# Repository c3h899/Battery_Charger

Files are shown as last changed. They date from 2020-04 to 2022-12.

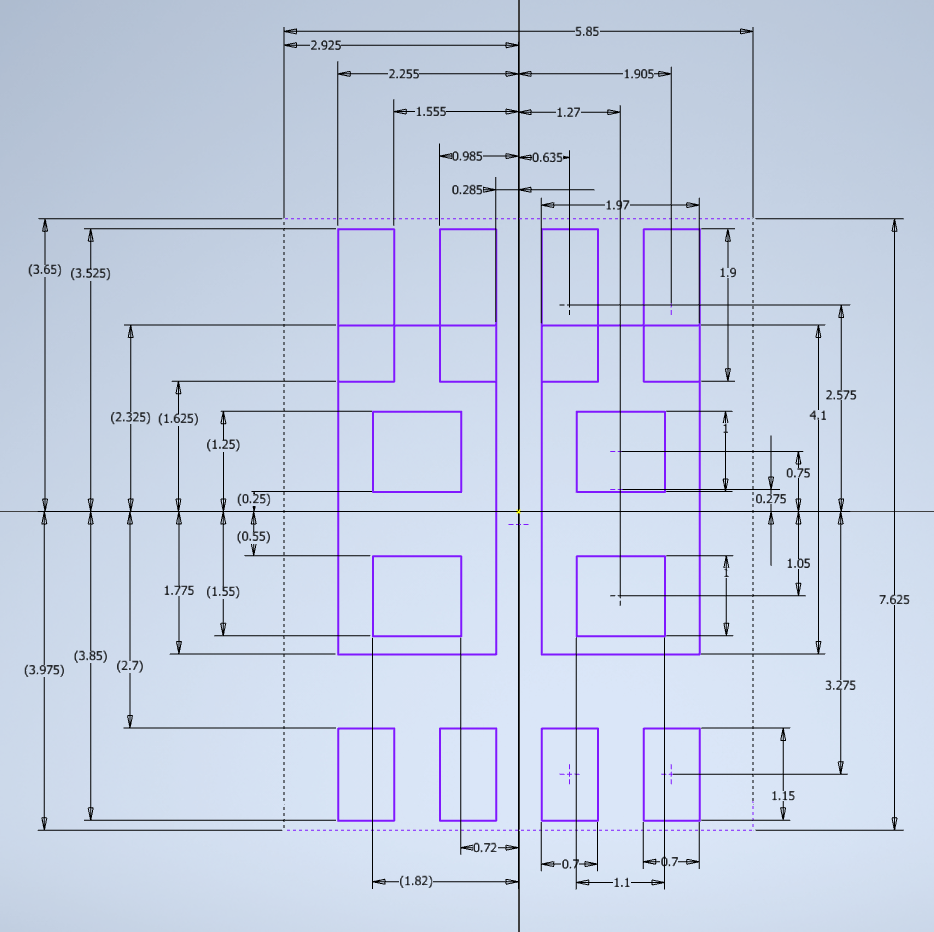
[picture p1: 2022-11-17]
DataSheets/Abs_vs_Center+Dist.PNG

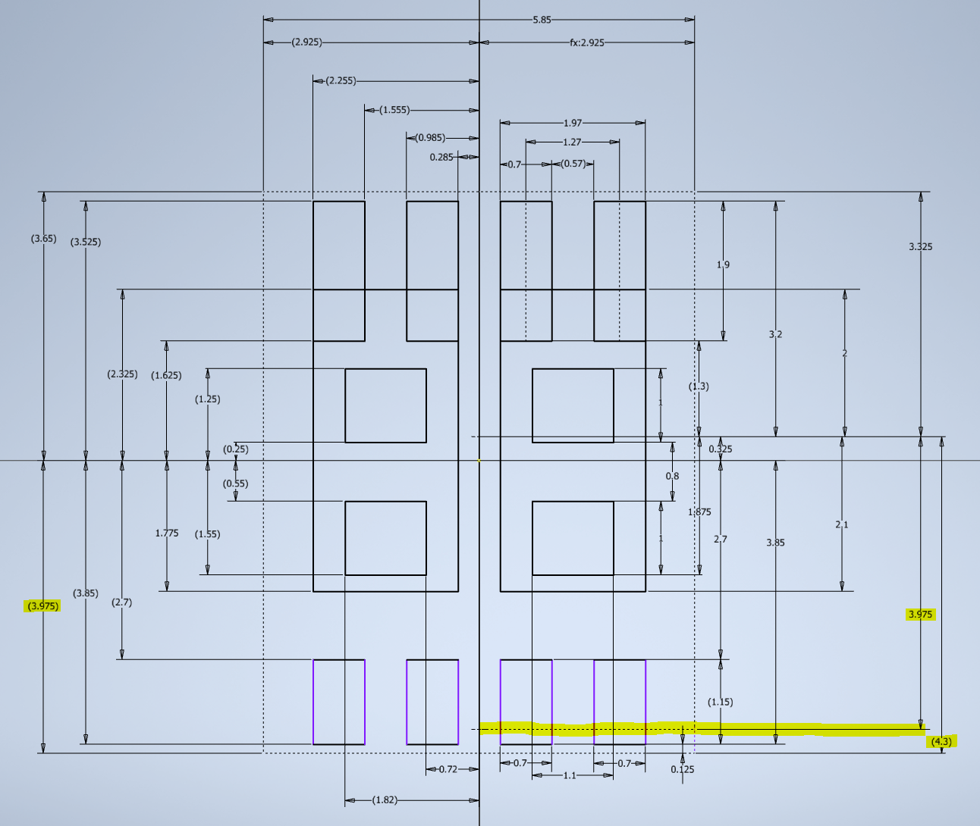
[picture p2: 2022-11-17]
DataSheets/Direct_Compair.PNG

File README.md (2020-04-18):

# Battery_Charger
- Battery Charger for (14.4 and 18.0) V NiMH Tool Batteries *Experimental*
- Requires External 24+ V, 2 A, DC power supply.

## Revision 3
- Adjusted Footprints.
- Bias network for RV1 adjusted.
- Bleed resistors added to large capacitors.
- Cascode circuitry added to +BATT monitoring to protect MAX713 sense input.
- D2 replaced with Q2 to provide more ideal diode behavior and provide reverse input protection.
- External temperature monitoring circuitry added.
- Low pass RC filters added to +BATT and -BATT sensing pins.
- Reverse input protection added to the DC input and Battery Outputs using P-Channel power MOSFETs.

## Revision 2
- Restructured board to have separate analog and switching ground planes (stared)

## Prototype 0
- Resistor Footprints are WAY too big.
- MAX713 Will regulate voltage across BAT- to BAT+ when measured using resistive load.
- Device successfully achieves current regulation during fast charge.
- At 24 V DC Input the LM7805 Gets hot, may need heatsink.
- Q2 was originally a 1N4001; Replace with 1N5821 due to excessive heating.
- Target Batteries get HOT near end-of charge sequence.
- Device has **NOT** been observed to perform DV/dt charge termination.
- In absence of reverse input protection, installing a charged battery backwards will destroy R7...R10.

## Revision 0
- Design is experimental, based on MAX713 Charge Controller.
- Concept: Replace the Linear Regulated Supply with a Buck Converter.
- Design is intended to charge at C/2 (~1.8 A)
- No use of temperature feedback is employed.
- No effort is made to reverse-input protect board.

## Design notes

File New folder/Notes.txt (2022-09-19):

NiCd
---
Charged ~1.6 V

NiMH
---
DV Goes Negative
Charged ~1.5 V

Universal
---
Undervolt 1.0 V (Arbitrary)
Nominal 1.2 V
Charged 1.5 V
DESIGN MAX 1.7 V

Trickel ~ 0.05 C
Standard Charge ~ 0.1 C
Quick Charge ~ 0.5 C
Rapid Charge ~ 1.0 C

Cell Counts

14.4 V Nominal
---
12 Cells
18 V @ 1.5 V
20.4 V @ 1.7

18.0 V Nominal
---
15 Cells
22.5 V @ 1.5 V

DESIGN
---
Series Buck + Boost Arangement
Goals: Continuous Conduction
Assume 3.6 Ah Capacity
1.8 A Design Current (1/2 C Quick Charge)
180 mA (1/20 C Trickel)

Frequency of Operation 300 kHz

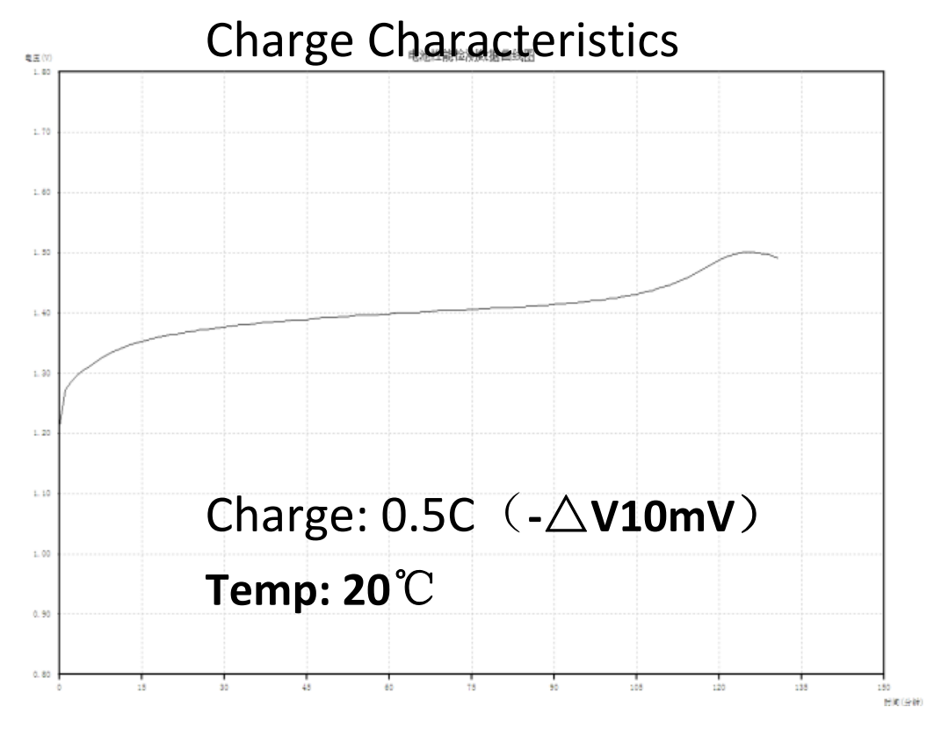
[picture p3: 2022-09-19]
New folder/NiMH Sub-S.PNG

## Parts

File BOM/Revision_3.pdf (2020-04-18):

Quantity Type | Description | Manufacturer Part Number | Vendor | Vendor Part Number | Unit Price Extended Price
2 | Capacitor | CAP CER 10000PF 100V X7R RADIAL | C315C103K1R5TA7301 | Digi‐Key | 399‐9857‐1‐ND | 0.27 | 0.54
1 | Capacitor | CAP ALUM 470UF 20% 50V RADIAL | ESW477M050AL3AA | Digi‐Key | 399‐6117‐ND | 1.04 | 1.04
3 | Capacitor | CAP ALUM 10UF 10% 63V RADIAL | UKL1J100KED | Digi‐Key | 493‐14491‐ND | 0.42 | 1.26
3 | Capacitor | CAP ALUM 1UF 10% 100V RADIAL | UKL2A010KDD | Digi‐Key | 493‐15407‐ND | 0.35 | 1.05
1 | Diode Schottky | DIODE SCHOTTKY 30V 3A DO201AD | 1N5821RLG | Digi‐Key | 1N5821RLGOSCT‐ND | 0.40 | 0.40
1 | IC | IC REG BUCK ADJ 3A TO263‐7 | LM2676SX‐ADJ/NOPB | Digi‐Key | LM2676SX‐ADJ/NOPBCT‐ND | 4.77 | 4.77
1 | IC | IC REG LINEAR 5V 1A TO220‐3 | LM7805CT/NOPB | Digi‐Key | 296‐47192‐ND | 1.54 | 1.54
1 | IC | IC BATT FASTCHRG NICD/NIMH16SOIC | MAX713CSE+ | Digi‐Key | MAX713CSE+‐ND | 5.87 | 5.87
1 | Inductor | FIXED IND 68UH 7.3A 25 MOHM | 1468373C | Digi‐Key | 811‐3857‐ND | 2.62 | 2.62
2 | MOSFET P.Ch | MOSFET P‐CH 60V 27A TO‐220 | FQP27P06 | Digi‐Key | FQP27P06‐ND | 1.41 | 2.82
1 | NPN | TRANS NPN 40V 0.2A TO92 | 2N3904‐AP | Digi‐Key | 2N3904‐APCT‐ND | 0.17 | 0.17
1 | Potentiometer | POT 10K OHM 1/20W CARBON LINEAR | PTV09A‐4020U‐B103 | Digi‐Key | PTV09A‐4020U‐B103‐ND | 0.83 | 0.83
3 | Resistor | RES 100K OHM 0.4W 1% AXIAL | MBA02040C1003FRP00 | Digi‐Key | BC100KXCT‐ND | 0.24 | 0.72
8 | Resistor | RES 27K OHM 0.4W 1% AXIAL | MBA02040C2702FCT00 | Digi‐Key | BC3267CT‐ND | 0.24 | 1.92
2 | Resistor | RES 10K OHM 1/4W 1% AXIAL | RNMF14FTC10K0 | Digi‐Key | S10KCACT‐ND | 0.10 | 0.20
3 | Resistor | RES 18K OHM 1/4W 1% AXIAL | RNMF14FTC18K0 | Digi‐Key | S18KCACT‐ND | 0.10 | 0.30
2 | Resistor | RES 1K OHM 1/4W 1% AXIAL | RNMF14FTC1K00 | Digi‐Key | S1KCACT‐ND | 0.10 | 0.20
1 | Resistor | RES 43K OHM 1/4W 1% AXIAL | RNMF14FTC43K0 | Digi‐Key | S43KCACT‐ND | 0.10 | 0.10
4 | Resistor | RES 0.56 OHM 1W 5% AXIAL | RSMF1JTR560 | Digi‐Key | RSMF1JTR560CT‐ND | 0.24 | 0.96
1 | Resistor NTC | THERMISTOR NTC 10KOHM 3977K BEAD | NTCLE100E3103JB0 | Digi‐Key | BC2301‐ND | 0.69 | 0.69
3 | PCB | Printed Circuit Board | Charge_Board_R3 | OshPark | | 14.93 | 44.79
| | | | | | | 72.79
| | | | | | | 6.01
| Shipping | | | OshPark | | 6.70 | 6.70
| Shipping | | | Digi‐Key | | 8.99 | 8.99
| | | | | | | 94.49

Sub‐Total
Sales Tax

Total

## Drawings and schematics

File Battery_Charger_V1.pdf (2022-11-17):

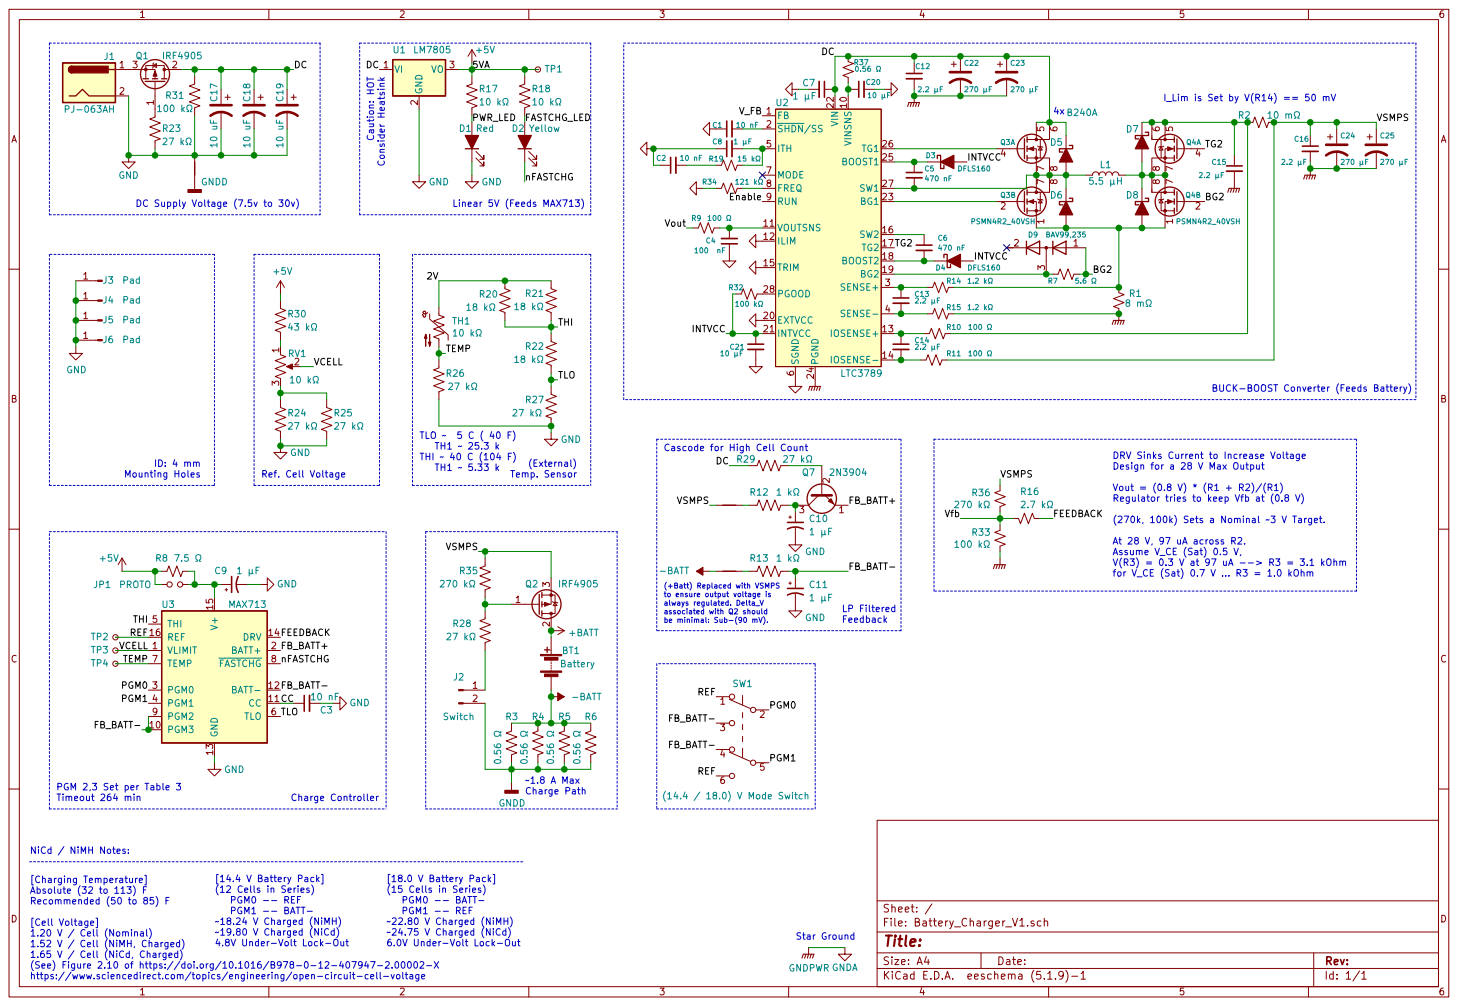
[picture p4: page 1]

DC Caution: HOT Consider Heatsink

I_Lim is Set by V(R14) == 50 mV

DC Supply Voltage (7.5v to 30v)

BUCK-BOOST Converter (Feeds Battery)

LP Filtered Feedback Cascode for High Cell Count

DRV Sinks Current to Increase Voltage
Design for a 28 V Max Output

Vout = (0.8 V) * (R1 + R2)/(R1)
Regulator tries to keep Vfb at (0.8 V)

(270k, 100k) Sets a Nominal 3 V Target. At 28 V, 97 uA across R2. Assume V_CE (Sat) 0.5 V,

(+Batt) Replaced with VSMPS
to ensure output voltage is always regulated. Delta_V

PGM 2,3 Set per Table 3 Timeout 264 min

[Charging Temperature]
Absolute (32 to 113) F
Recommended (50 to 85) F
[Cell Voltage]
1.20 V / Cell (Nominal)
1.52 V / Cell (NiMH, Charged)
1.65 V / Cell (NiCd, Charged)
(See) Figure 2.10 of https://doi.org/10.1016/B978-0-12-407947-2.00002-X
https://www.sciencedirect.com/topics/engineering/open-circuit-cell-voltage

[18.0 V Battery Pack]
(15 Cells in Series)
PGM0 -- BATT-
PGM1 -- REF
22.80 V Charged (NiMH)
24.75 V Charged (NiCd) 6.0V Under-Volt Lock-Out

19.80 V Charged (NiCd) 4.8V Under-Volt Lock-Out

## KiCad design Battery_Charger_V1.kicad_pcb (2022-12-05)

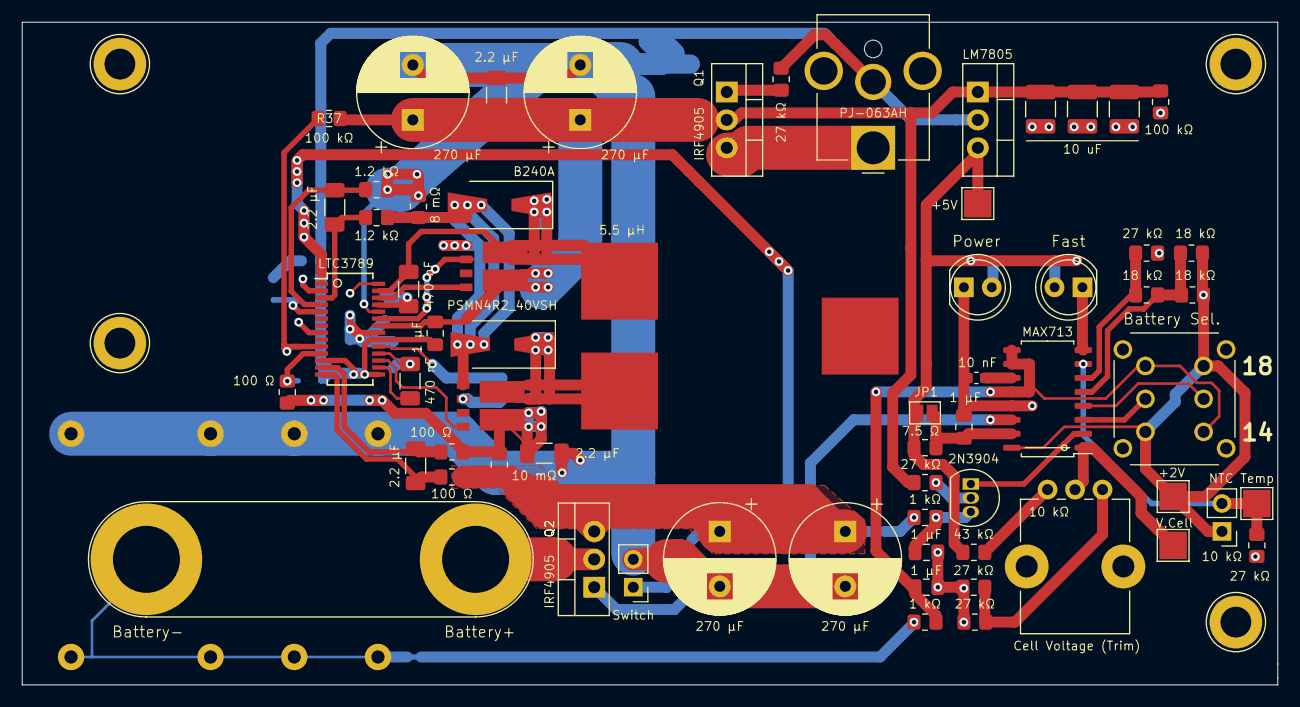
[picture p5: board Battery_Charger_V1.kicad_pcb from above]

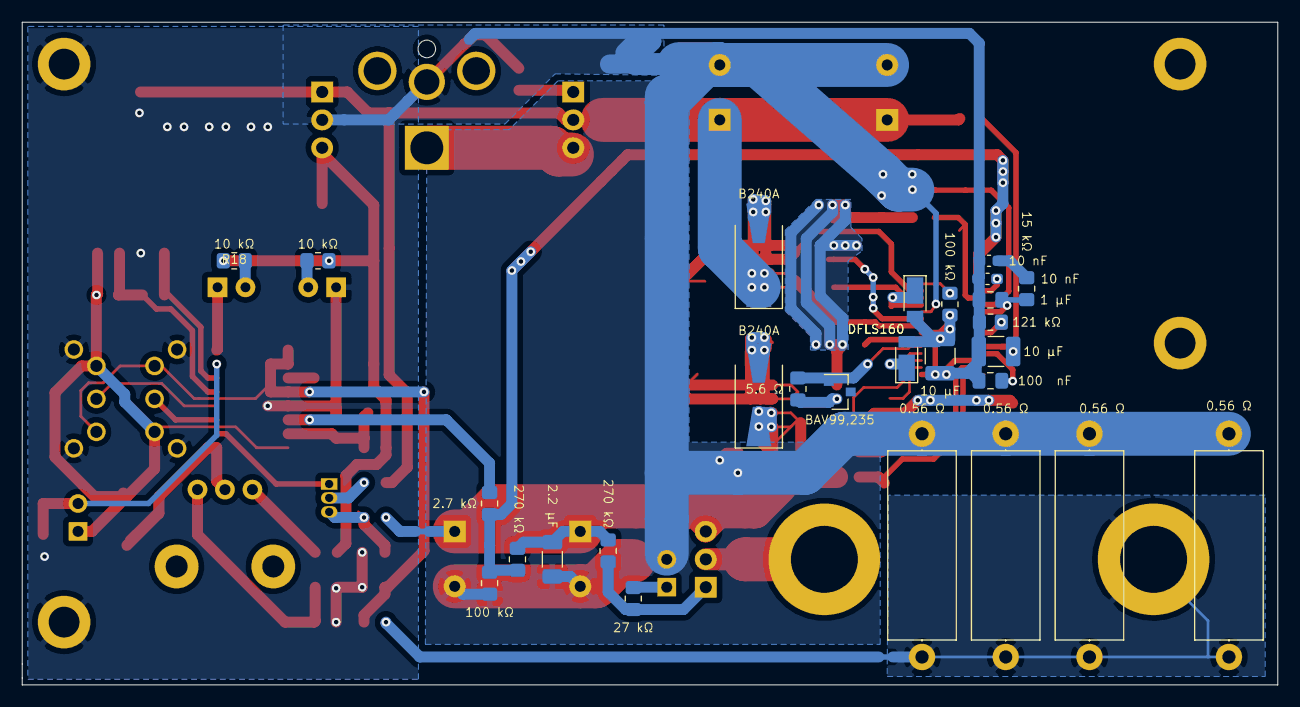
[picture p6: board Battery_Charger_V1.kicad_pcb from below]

Board: 2 copper layers, 114.3 x 60.3 mm, 98 parts (30 on the bottom side), 57 nets.

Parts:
BT1: Battery; Banana_Jack_2Pin
C1, C2, C3: 10 nF; C_0603_1608Metric_Pad1.08x0.95mm_HandSolder
C4: 100 nF; C_0805_2012Metric_Pad1.18x1.45mm_HandSolder
C5, C6: 470 nF; C_1206_3216Metric_Pad1.33x1.80mm_HandSolder
C7, C8, C9, C10, C11: 1 μF; C_0805_2012Metric_Pad1.18x1.45mm_HandSolder
C12, C13, C14, C15, C16: 2.2 μF; C_1206_3216Metric_Pad1.33x1.80mm_HandSolder
C17, C18, C19: 10 uF; C_1210_3225Metric_Pad1.33x2.70mm_HandSolder
C20, C21: 10 μF; C_1210_3225Metric_Pad1.33x2.70mm_HandSolder
C22, C23, C24, C25: 270 μF; CP_Radial_D10.0mm_P5.00mm
D1: Red; LED_D5.0mm
D2: Yellow; LED_D5.0mm
D3, D4: DFLS160; D_PowerDI-123
D5, D6, D7, D8: B240A; D_SMA-SMB_Universal_Handsoldering
D9: BAV99,235; D_SOT-23_ANK
J1: PJ-063AH; BarrelJack_CUI_PJ-063AH_Horizontal_CircularHoles
J2: Switch; PinHeader_1x02_P2.54mm_Vertical
J3, J4, J5, J6: Pad; TestPoint_Loop_D3.80mm_Drill2.8mm
JP1: PROTO; SolderJumper-2_P1.3mm_Open_Pad1.0x1.5mm
L1: 5.5 μH; 2818
NT1: Net-Tie; NetTie-2_SMD_Pad2.0mm
NT2, NT3: Net-Tie; NetTie-2_SMD_Pad0.5mm
Q1, Q2: IRF4905; TO-220-3_Vertical
Q3, Q4: PSMN4R2_40VSH; LFPAK56D
Q7: 2N3904; TO-92_Inline
R1: 8 mΩ; R_0805_2012Metric_Pad1.20x1.40mm_HandSolder
R2: 10 mΩ; R_0805_2012Metric_Pad1.20x1.40mm_HandSolder
R3, R4, R5, R6: 0.56 Ω; R_Axial_DIN0617_L17.0mm_D6.0mm_P20.32mm_Horizontal
R7: 5.6 Ω; R_0805_2012Metric_Pad1.20x1.40mm_HandSolder
R8: 7.5 Ω; R_0805_2012Metric_Pad1.20x1.40mm_HandSolder
R9, R10, R11: 100 Ω; R_0805_2012Metric_Pad1.20x1.40mm_HandSolder
R12, R13: 1 kΩ; R_0805_2012Metric_Pad1.20x1.40mm_HandSolder
R14, R15: 1.2 kΩ; R_0805_2012Metric_Pad1.20x1.40mm_HandSolder
R16: 2.7 kΩ; R_0805_2012Metric_Pad1.20x1.40mm_HandSolder
R17, R18: 10 kΩ; R_0805_2012Metric_Pad1.20x1.40mm_HandSolder
R19: 15 kΩ; R_0805_2012Metric_Pad1.20x1.40mm_HandSolder
R20, R21, R22: 18 kΩ; R_0805_2012Metric_Pad1.20x1.40mm_HandSolder
R23, R24, R25, R26, R27, R28, R29: 27 kΩ; R_0805_2012Metric_Pad1.20x1.40mm_HandSolder
R30: 43 kΩ; R_0805_2012Metric_Pad1.20x1.40mm_HandSolder
R31, R32, R33, R37: 100 kΩ; R_0805_2012Metric_Pad1.20x1.40mm_HandSolder
R34: 121 kΩ; R_0805_2012Metric_Pad1.20x1.40mm_HandSolder
R35, R36: 270 kΩ; R_0805_2012Metric_Pad1.20x1.40mm_HandSolder
RV1: 10 kΩ; Potentiometer_Bourns_PTV09A-1_Single_Vertical
SW1: (14.4 / 18.0) V Mode Switch; DPDT
TH1: 10 kΩ; PinHeader_1x02_P2.54mm_Vertical
TP1, TP2, TP3, TP4: TestPoint_Small; TestPoint_Pad_2.5x2.5mm
U1: LM7805; TO-220-3_Vertical
U2: LTC3789; SSOP-28_3.9x9.9mm_P0.635mm
U3: MAX713; SOIC-16_4.55x10.3mm_P1.27mm

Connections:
+5V: JP1.1, R8.2, R17.2, R18.2, R30.1, TP1.1, U1.3
+BATT: BT1.1, Q2.2
-BATT: BT1.2, NT3.1, R3.1, R4.1, R5.1, R6.1
/BG2: D9.3, Q4.2, R7.1
/CC: C3.1, U3.11
/DC: C7.1, C12.1, C17.1, C18.1, C19.1, C22.1, C23.1, D5.1, Q1.2, Q3.5, Q3.6, R29.2, R31.2, R37.2, U1.1, U2.22
/FASTCHG_LED: D2.2, R18.1
/FB_BATT+: Q7.1, U3.2
/FB_BATT-: C11.1, R13.1, SW1.3, SW1.4, U3.9, U3.10, U3.12
/FEEDBACK: R16.1, U3.14
/INTVCC: C21.1, D3.2, D4.2, R32.2, U2.21
/PGM0: SW1.2, U3.3
/PGM1: SW1.5, U3.4
/PWR_LED: D1.2, R17.1
/REF: R20.1, R21.2, SW1.1, SW1.6, TH1.1, TP2.1, U3.16
/TEMP: R26.1, TH1.2, TP4.1, U3.7
/TG2: Q4.4, U2.17
/THI: R20.2, R21.1, R22.2, U3.5
/TLO: R22.1, R27.1, U3.6
/VCELL: RV1.2, TP3.1, U3.1
/VSMPS: C16.1, C24.1, C25.1, NT2.1, Q2.3, R2.2, R11.1, R35.2, R36.1
/V_FB: R16.2, R33.1, R36.2, U2.1
/Vout: C15.1, D7.1, Q4.5, Q4.6, R2.1, R9.2, R10.1
/nFASTCHG: D2.1, U3.8
GND: C1.1, C2.1, C3.2, C4.1, C7.2, C8.1, C9.2, C10.2, C11.2, C17.2, C18.2, C19.2, C20.2, C21.2, D1.1, J1.2, J3.1, J4.1, NT1.1, R23.1, R24.2, R25.2, R26.2, R27.2, R31.1, R34.2, SW1.0, U1.2, U2.6, U2.12, U2.15, U2.20, U3.13
GNDPWR: C12.2, C15.2, C16.2, C22.2, C23.2, C24.2, C25.2, J2.2, NT1.2, R1.1, R3.2, R4.2, R5.2, R6.2, R15.1, R33.2, U2.24
unnamed: C1.2, U2.2
unnamed: C2.2, R19.2
unnamed: C4.2, R9.1, U2.11
unnamed: C5.1, D3.1, U2.25
unnamed: C5.2, D5.2, D6.1, L1.1, Q3.7, Q3.8, U2.27
unnamed: C6.1, U2.16
unnamed: C6.2, D4.1, U2.18
unnamed: C8.2, R19.1, U2.5
unnamed: C9.1, JP1.2, R8.1, U3.15
unnamed: C10.1, Q7.3, R12.1
unnamed: C13.1, R14.2, U2.3
unnamed: C13.2, R15.2, U2.4
unnamed: C14.1, R10.2, U2.13
unnamed: C14.2, R11.2, U2.14
unnamed: C20.1, R37.1, U2.10
unnamed: D6.2, D8.2, Q3.1, Q4.1, R1.2, R14.1
unnamed: D7.2, D8.1, L1.2, Q4.7, Q4.8
unnamed: D9.2, R7.2, U2.19
unnamed: J1.1, Q1.3
unnamed: J2.1, R28.1
unnamed: NT2.2, R12.2
unnamed: NT3.2, R13.2
unnamed: Q1.1, R23.2
unnamed: Q2.1, R28.2, R35.1
unnamed: Q3.2, U2.23
unnamed: Q3.4, U2.26
unnamed: Q7.2, R29.1
unnamed: R24.1, R25.1, RV1.3
unnamed: R30.2, RV1.1
unnamed: R32.1, U2.28
unnamed: R34.1, U2.8

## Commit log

2020-04-18 Initial Upload of Designs
    [Charge_Board.kicad_pcb, Charge_Board.sch]
2020-04-18 Added BOM
    [Charge_Board.sch, Revision_3.xlsx]
2022-11-10 Updated Design
    Reverted to MAX713 controller.
    Design is (Mostly) a direct iteration on the master branch.
    TODO: Review MAX713 behavior in presence of damaged cells.
    [Battery_Charger_V1.sch]
2022-11-13 Schematic Revision
    Added a mode switch for improved end-user experience.
    [Low_Noise.kicad_pcb, Low_Noise.kicad_sch, Low_Noise.sch]
2022-11-13 Corrected Q1
    P-Channel MOSFET was oriented incorrectly.
    [Battery_Charger_V1.sch]
2022-11-17 Draft PCB
    Minor edits to schematic.
    PCB is **NOT** fully routed.
    [Battery_Charger_V1.sch]
2022-11-18 Draft PCB(2)
    Incomplete
    Routing has begun to consider current associated with circuit traces.
    [Battery_Charger_V1.kicad_pcb]
2022-11-19 Draft PCB(3)
    Pre-DRC
    [Battery_Charger_V1.kicad_pcb, Battery_Charger_V1.sch]
2022-12-05 Revised Switch Footprint
    [Battery_Charger_V1-B_Cu.gbr, Battery_Charger_V1-B_Mask.gbr, Battery_Charger_V1-B_Paste.gbr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]
